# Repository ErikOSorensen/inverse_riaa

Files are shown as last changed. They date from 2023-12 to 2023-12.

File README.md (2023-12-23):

#  Inverse RIAA filter

Inverse RIAA filter for testing phono preamps. If we want to test phono preamps with
a soundcard interface, we need a lot of attenuation of the soundcard output - and we
would also like to invert the RIAA filtering that is part of an ordinary phono 
preamp such that the soundcard input receives a signal which, under ideal operation,
has a constant amplitude as the frequency varies.

## The schematic

The design is a simple and direct implementation of the suggestion of Lipshitz and Jung (1980),
in their paper "A High Accuracy Inverse RIAA Network" (Figure 3). I have adapted it by paralleling
some parts for greater accuracy.

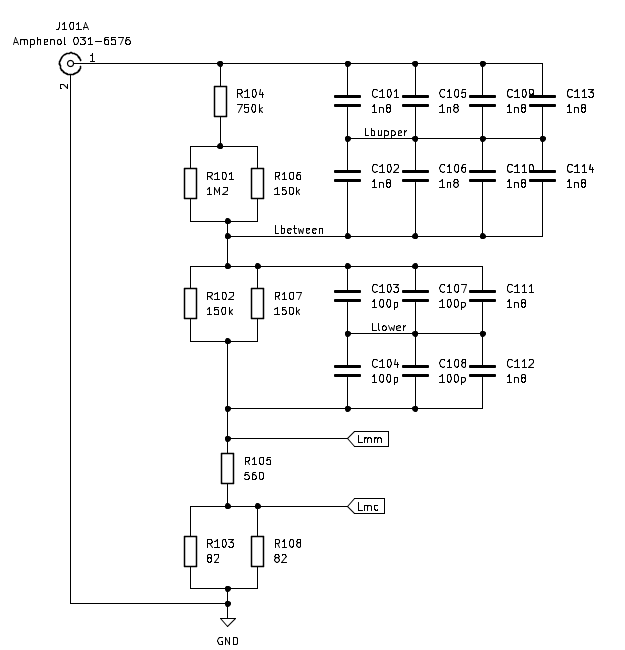
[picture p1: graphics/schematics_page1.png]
One channel of the filter


## First physical build

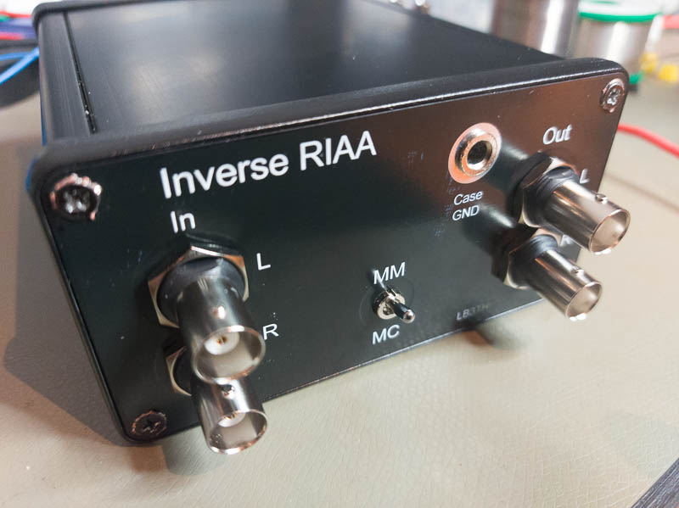
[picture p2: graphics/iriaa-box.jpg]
Picture of assembled filter in a box


This is a passive filter. I have built one into a Hammond 1455N1201BK extruded box,
with isolated (stereo) BNCs in and out. There is an option to add 20 dB of attenuation
for testing MC phono preamps.

For this first build I have used Susumu 0.5% resistors and Murata 1% capacitors.

## Characterization

Measurement of the attenuation and comparison to what we should expect (calculated
in LT spice) indicates that the filter is within 0.2 dB of the correct curve over
most of the frequency range.

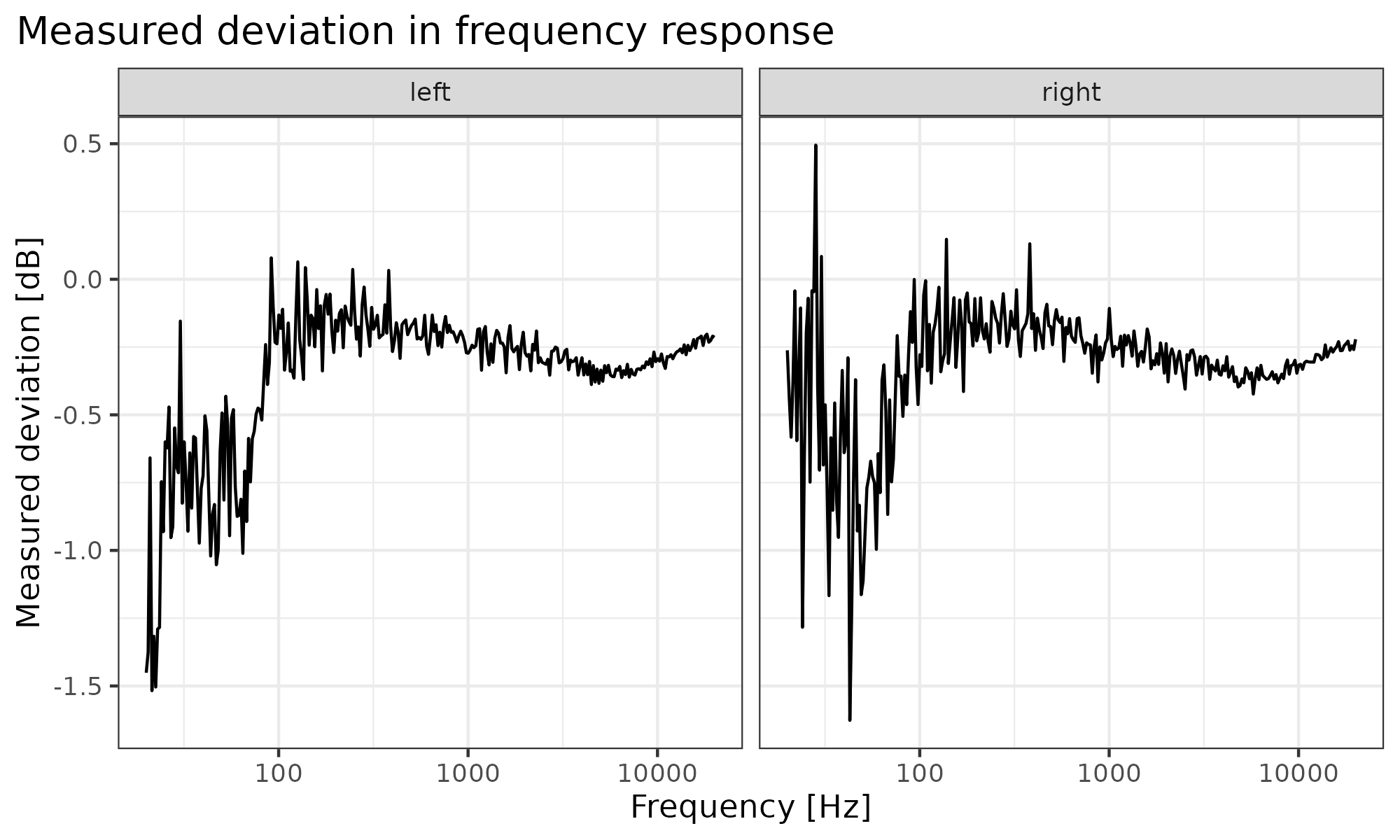
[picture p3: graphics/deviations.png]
Measurements with Analog Discovery 2


Note that the measurements (in the MM path) were taken with an Analog Discovery
2, which only has a 14 bit ADC, so there is a lot of noise and quantization
error at the lower frequencies where attenuation is greatest. With the AD2, the
dynamic range is not sufficient to test the MC path, but since that only
involves a single extra resistor (which can be verified with a DMM), that
shouldn't involve any additional concerns.

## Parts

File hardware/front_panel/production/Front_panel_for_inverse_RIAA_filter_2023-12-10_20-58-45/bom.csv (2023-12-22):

Designator | Footprint | Quantity | Value | LCSC Part #
H101, H102, H103, H104 | MountingHole_3.2mm_M3_DIN965_Pad_TopBottom | 4 | MountingHole_Pad
H105 | MountingHole_6.4mm_M6_DIN965_Pad_TopBottom | 1 | MountingHole_Pad

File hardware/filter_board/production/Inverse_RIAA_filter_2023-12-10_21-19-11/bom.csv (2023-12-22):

Designator | Footprint | Quantity | Value | LCSC Part #
C101, C102, C105, C106, C109, C110, C111, C112, C113, C114, C115, C116, C119, C120, C123, C124, C125, C126, C127, C128 | 0805 | 20 | 1n8
C103, C104, C107, C108, C117, C118, C121, C122 | 0805 | 8 | 100p
J101, J102 | BNC_Amphenol_031-6575_Horizontal | 2 | Amphenol 031-6576
R101, R109 | 0805 | 2 | 1M2
R102, R106, R107, R110, R114, R115 | 0805 | 6 | 150k
R103, R108, R111, R116 | 0805 | 4 | 82
R104, R112 | 0805 | 2 | 750k
R105, R113 | 0805 | 2 | 560
SW101 | 34ADP12B4M7GT | 1 | Grayhill 34ADP12B4M7GT

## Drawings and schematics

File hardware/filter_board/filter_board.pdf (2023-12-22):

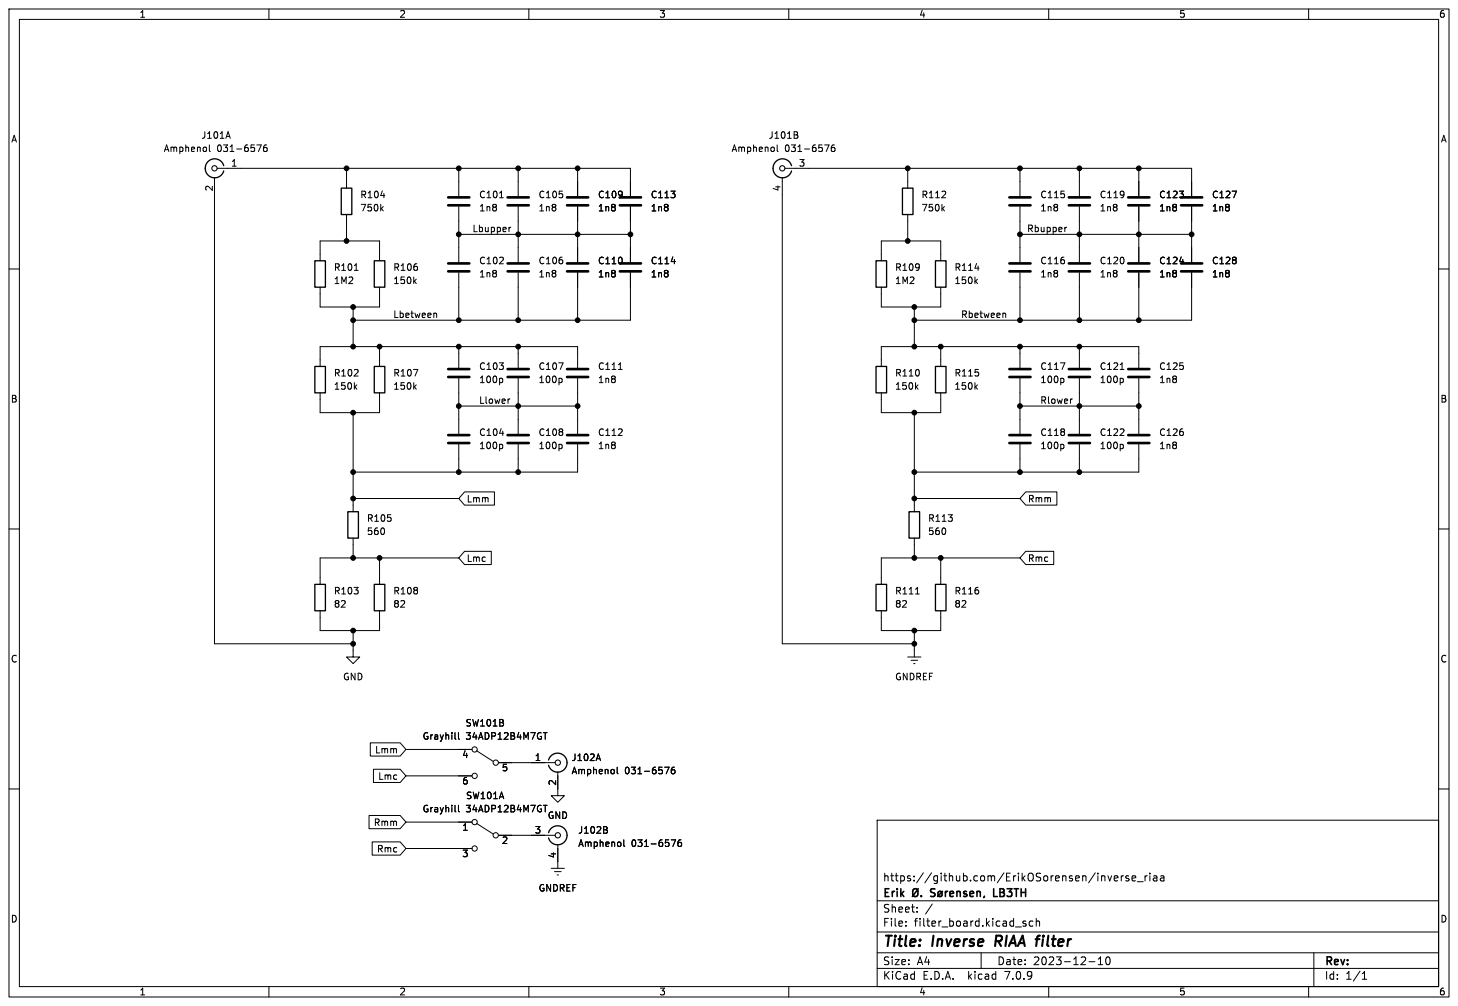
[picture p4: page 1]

https://github.com/ErikOSorensen/inverse_riaa

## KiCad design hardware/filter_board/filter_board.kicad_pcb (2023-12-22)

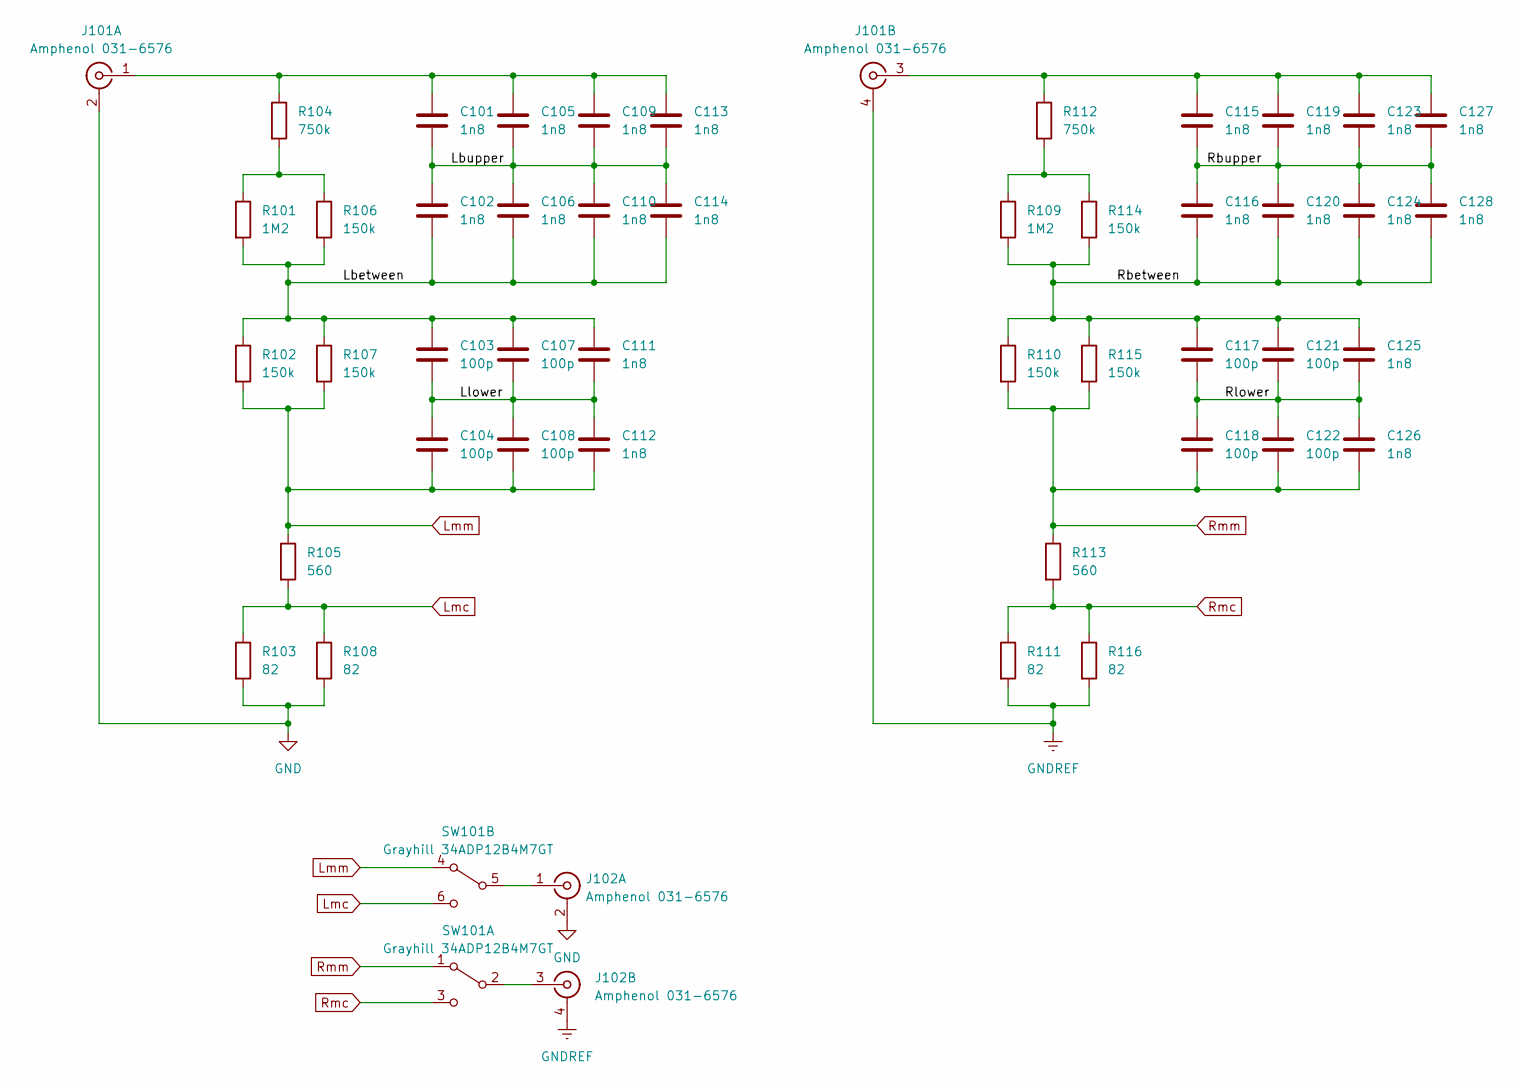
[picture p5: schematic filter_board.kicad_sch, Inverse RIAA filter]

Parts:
C101, C102, C105, C106, C109, C110, C111, C112, C113, C114, C115, C116, C119, C120, C123, C124, C125, C126, C127, C128: 1n8; C_0805_2012Metric
C103, C104, C107, C108, C117, C118, C121, C122: 100p; C_0805_2012Metric
J101, J102: Amphenol 031-6576; BNC_Amphenol_031-6575_Horizontal
R101, R109: 1M2; R_0805_2012Metric
R102, R106, R107, R110, R114, R115: 150k; R_0805_2012Metric
R103, R108, R111, R116: 82; R_0805_2012Metric
R104, R112: 750k; R_0805_2012Metric
R105, R113: 560; R_0805_2012Metric
SW101: Grayhill 34ADP12B4M7GT; 34ADP12B4M7GT

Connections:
/Lbetween: C102.2, C103.1, C106.2, C107.1, C110.2, C111.1, C114.2, R101.2, R102.1, R106.2, R107.1
/Lbupper: C101.2, C102.1, C105.2, C106.1, C109.2, C110.1, C113.2, C114.1
/Llower: C103.2, C104.1, C107.2, C108.1, C111.2, C112.1
/Rbetween: C116.2, C117.1, C120.2, C121.1, C124.2, C125.1, C128.2, R109.2, R110.1, R114.2, R115.1
/Rbupper: C115.2, C116.1, C119.2, C120.1, C123.2, C124.1, C127.2, C128.1
/Rlower: C117.2, C118.1, C121.2, C122.1, C125.2, C126.1
GND: J101.2 (Ext1), J102.2 (Ext1), R103.2, R108.2
GNDREF: J101.4 (Ext2), J102.4 (Ext2), R111.2, R116.2
Lmc: R103.1, R105.2, R108.1, SW101.6 (C)
Lmm: C104.2, C108.2, C112.2, R102.2, R105.1, R107.2, SW101.4 (A)
unnamed: C101.1, C105.1, C109.1, C113.1, J101.1 (In1), R104.1
unnamed: C115.1, C119.1, C123.1, C127.1, J101.3 (In2), R112.1
unnamed: J102.1 (In1), SW101.5 (B)
unnamed: J102.3 (In2), SW101.2 (B)
unnamed: R101.1, R104.2, R106.1
unnamed: R109.1, R112.2, R114.1
Rmc: R111.1, R113.2, R116.1, SW101.3 (C)
Rmm: C118.2, C122.2, C126.2, R110.2, R113.1, R115.2, SW101.1 (A)

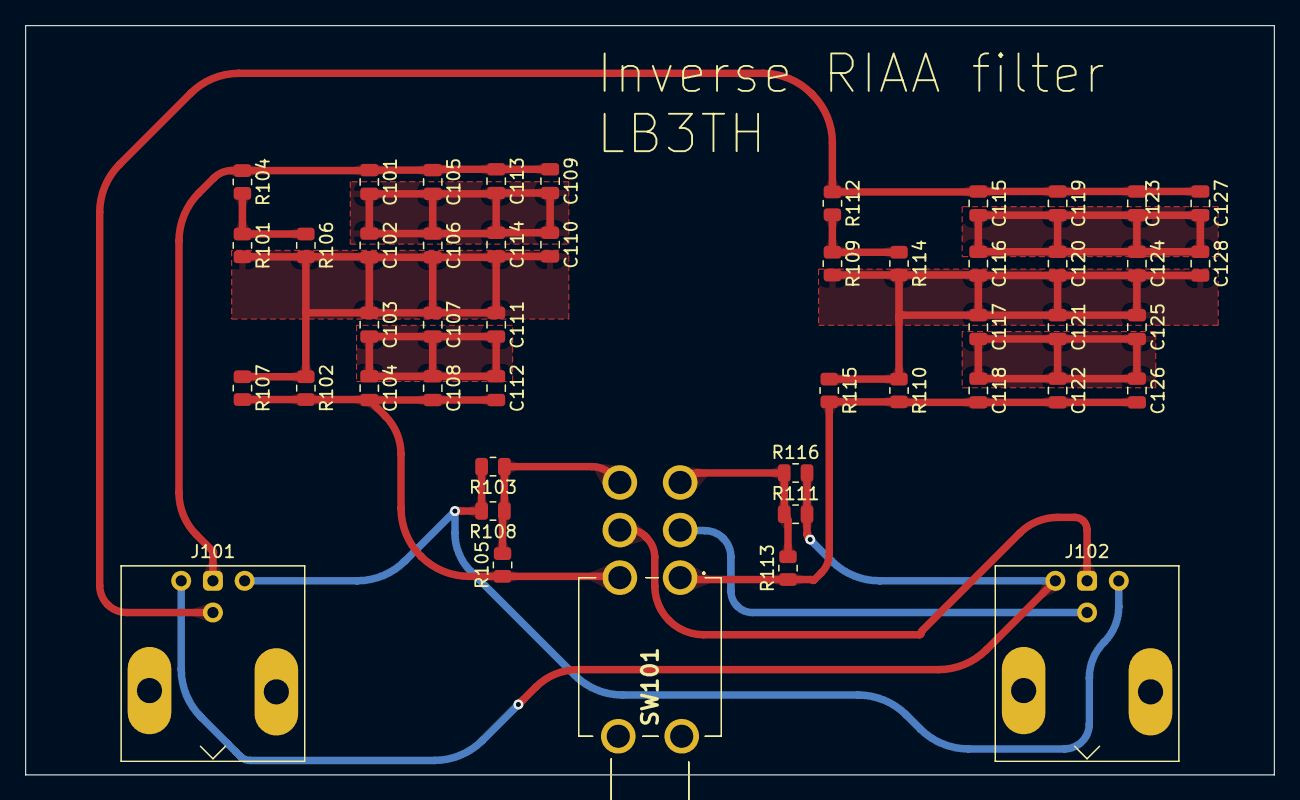
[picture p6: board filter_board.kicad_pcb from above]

Board: 2 copper layers, 100.0 x 60.0 mm, 47 parts (0 on the bottom side), 18 nets.

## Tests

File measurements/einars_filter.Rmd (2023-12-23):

---
title: "Characterizing a built up filter"
author: "Erik Ø. Sørensen"
date: "`r Sys.Date()`"
output: html_document
---

```{r setup, include=FALSE}
knitr::opts_chunk$set(echo = TRUE)
library(tidyverse)
library(scales)
```

I made an attempt at getting my fancy audio interface (MOTU M4) to work
with REW, but only ended up frustrated. Instead I grabbed my Analog
Discovery 2, which can run in network analyzer mode using the "Waveforms" 
software. Unfortunately, the the analog discovery only has a 14 bit ADC
and I haven't got an easy to use amplifier within reach, so testing
the MC output of the filter won't be possible. I also expect a substantial
amount of noise in the lower frequency, where there should be more than
60 dB of attenuation.

The setup is: BNC cable connecting output 1 from the Analog Discovery 2
generator 1 to the input of the filter, and similarly a BNC cable from the
filter output back to the oscope input 1 on the Analog Discovery.

I have used the LT-spice software to calculate the expected true
curve (under assumption of a low impedance signal generator (100 Ohm) and a
high impedance receiver at the output of the filter).

```{r include=FALSE}
lns <- readLines("ltspice_iriaa.txt", n=-1, encoding="UTF-8")
names <- strsplit(lns[1],"\t")
df_LT <- tibble(frequency = numeric(),
                vmc_db = numeric(),
                vmc_ph = numeric(),
                vmm_db = numeric(),
                vmm_ph = numeric())
for (row in lns[-1]) {
  xs <- strsplit(row, '\t')[[1]]
  f <- as.double( xs[1] )
  x1 <- str_extract_all(xs[2], "[+-]?(\\d+([.]\\d*)?(e[+-]?\\d+)?|[.]\\d+(e[+-]?\\d+)?)")[[1]]
  x2 <- str_extract_all(xs[3], "[+-]?(\\d+([.]\\d*)?(e[+-]?\\d+)?|[.]\\d+(e[+-]?\\d+)?)")[[1]]
  df_LT <- df_LT %>% add_row(frequency = f,
                             vmc_db = as.double(x1[1]),
                             vmc_ph = as.double(x1[2]),
                             vmm_db = as.double(x2[1]),
                             vmm_ph = as.double(x2[2]))
}
df_LT <- df_LT |> filter(frequency <=20000) |>
  mutate(freq_string = format(round(frequency,1), nsmall=1,trim=TRUE ))
```

```{r include=FALSE}
# Reading data from the analog discovery Waveforms software
mmr_df <- read_csv("2023-12-22T1922_R-MM.csv", comment = "#") |>
  mutate(channel = "right")
mml_df <- read_csv("2023-12-22T1924_L-MM.csv", comment = "#") |>
  mutate(channel = "left")
mm_df <- mmr_df |> bind_rows(mml_df) |>
  rename(freq = `Frequency (Hz)`,
         magnitude = `Channel 1 Magnitude (dB)`) |>
  mutate(freq_string = format(round(freq,1), nsmall=1,trim=TRUE))
df <- mm_df |> left_join(df_LT)
```

First, let's have a look at how the measurements compares to the calcuated
numbers from LT-spice:

```{r echo=FALSE}
df |> mutate(error_db = vmm_db -magnitude) |>
  ggplot(aes(x=frequency, y = error_db)) +
  geom_line() +
  theme_bw() +
  labs(x = "Frequency [Hz]", y = "Measured deviation [dB]",
       title = "Measured deviation in frequency response") +
  theme(plot.title.position = "plot") +
  scale_x_log10() +
  facet_wrap(~channel)
ggsave("../graphics/deviations.png", width = 2000, height = 1200, 
       units = "px", bg = "white")
```

We see that there is a lot of noise below 100Hz, which is not strange
taking the measurement equipment into account (and also some quantization error). Above 100Hz, most
of the measurements, in both channels, are about 0.25dB attenuated compared to the LT-spice numbers. This variation from the predicted numbers in the levels
isn't really a problem. 

Both channels have a slight dip around 5kHz, about 0.2dB down. This indicates
an issue with how the higher time constant is implemented. That it is the
same in both channels maybe indicates something systematic. 

As can be seen from the graph above, the channel balance is good. For 
reference, this is the deviation from perfect channel balance by frequency:

```{r echo=FALSE}
df_imbalance <- df |> pivot_wider(id_cols = frequency, names_from = channel, 
                                  values_from = magnitude) |>
  mutate(imbalance = left - right)
df_imbalance |> ggplot(aes(x=frequency, y = imbalance)) +
  geom_line() +
  theme_bw() +
  labs(x = "Frequency [Hz]", y = "Imbalance [dB]",
       title = "Measured left/right imbalance in frequency response") +
  theme(plot.title.position = "plot") +
  scale_x_log10() 

#|>
#  mutate(magnitude_difference = )
```

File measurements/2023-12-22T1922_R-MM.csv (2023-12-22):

#Digilent WaveForms Network Analyzer - Bode
#Device Name: Discovery2
#Serial Number: SN:210321A966DF
#Date Time: 2023-12-22 19:20:31.252
#Start: 20 Hz
#Stop: 20000 Hz
#Steps: 301
#Wavegen: Wavegen C1
#Amplification: 1 X
#Settle: 10 ms
#MinPeriods: 16
#Channel: Channel 1
#Range: 61.5666 V
#Offset: -0.00131367 V
#Relative: no
#
Frequency (Hz) | Channel 1 Magnitude (dB)
20.00000000000002 | -63.21240483696887
20.46585984561509 | -63.0111962036171
20.94257096101801 | -62.83539723489839
21.43038610475214 | -63.01471295308683
21.92956392286372 | -63.31366797250492
22.4403690860393 | -62.72861916947589
22.96307242993768 | -62.95698263593336
23.49795109879061 | -63.14948229844617
24.04528869234826 | -61.93537140291144
24.60537541624765 | -62.52691210595878
25.17850823588337 | -62.94507989912259
25.7649910338627 | -63.0311873714505
26.36513477112818 | -62.31085606503628
26.97925765183309 | -62.97305919682543
27.60768529205771 | -62.92406137232039
28.25075089245511 | -63.41805948772272
28.90879541491859 | -62.47578636989421
29.58216776336418 | -62.12033841827795
30.2712249687242 | -62.8567190806383
30.97633237824965 | -62.03363420864521
31.69786384922228 | -62.19991736822262
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

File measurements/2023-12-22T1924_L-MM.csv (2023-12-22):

#Digilent WaveForms Network Analyzer - Bode
#Device Name: Discovery2
#Serial Number: SN:210321A966DF
#Date Time: 2023-12-22 19:24:04.377
#Start: 20 Hz
#Stop: 20000 Hz
#Steps: 301
#Wavegen: Wavegen C1
#Amplification: 1 X
#Settle: 10 ms
#MinPeriods: 16
#Channel: Channel 1
#Range: 61.5666 V
#Offset: -0.00131367 V
#Relative: no
#
Frequency (Hz) | Channel 1 Magnitude (dB)
20.00000000000002 | -62.02315015504306
20.46585984561509 | -62.07181935362002
20.94257096101801 | -62.75904990438502
21.43038610475214 | -61.87026738447256
21.92956392286372 | -62.039878214778
22.4403690860393 | -61.82009396958888
22.96307242993768 | -62.00007398352741
23.49795109879061 | -61.97121895421777
24.04528869234826 | -62.4721567288188
24.60537541624765 | -62.24997560021257
25.17850823588337 | -62.54213102756057
25.7649910338627 | -62.47925539624806
26.36513477112818 | -62.58799940810997
26.97925765183309 | -62.06247730144138
27.60768529205771 | -62.05748029522961
28.25075089245511 | -62.37501238421191
28.90879541491859 | -62.18400166400603
29.58216776336418 | -62.11076411722314
30.2712249687242 | -62.61805550674933
30.97633237824965 | -61.89275416281588
31.69786384922228 | -62.06336826517565
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

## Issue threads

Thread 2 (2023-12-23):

Switch and BNC connectors too far back

ErikOSorensen, 2023-12-23:
The panel mount components should be further forward to account for the spacing effect of the plastic bezel.

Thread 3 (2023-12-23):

Grounding incomplete

ErikOSorensen, 2023-12-23:
With an anodized box, I should do more work to ensure that the case is well connected to the case. Should probably run a wire from the ground connection on the front panel to the bottom off the case and a separate connection to the sliding top.

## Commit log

2023-12-10 Filter board layout.
    [filter_board.kicad_pcb, filter_board.kicad_sch]
2023-12-10 Front panel for Hammond extruded case.
    [front_panel.kicad_pcb, front_panel.kicad_sch]
2023-12-22 Frequency response measurements (Analog Discovery 2).
    [2023-12-22T1922_R-MM.csv, 2023-12-22T1924_L-MM.csv]
2023-12-22 Syncronizing with hardware files.
    [filter_board.kicad_pcb, filter_board.kicad_sch, front_panel.kicad_pcb]
2023-12-22 Production files and updated README
    [bom.csv, designators.csv, positions.csv]
2023-12-22 Added github reference in schematic.
    [filter_board.kicad_sch]
